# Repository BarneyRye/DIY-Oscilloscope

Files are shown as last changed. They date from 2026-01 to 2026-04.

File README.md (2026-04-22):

# DIY Osciliscope
Design based on a **STM32F405RGT6**, with 2 options to connect up to 2 seperate leads. <br>
Used a 240x320 TFT ILI9341 screen module over SPI. <br>
[Example Screen: 2.8-inch SPI LCD Module 240 * 320 TFT Module ILI9341](https://www.amazon.co.uk/DIGISHUO-2-8-inch-ILI9341-occupies-Display/dp/B0DPZ3B171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) <br>
Max inputs of +/- 20V, 40Vpp. <br>
USB-C connection for power or streaming waveform to seprate device.

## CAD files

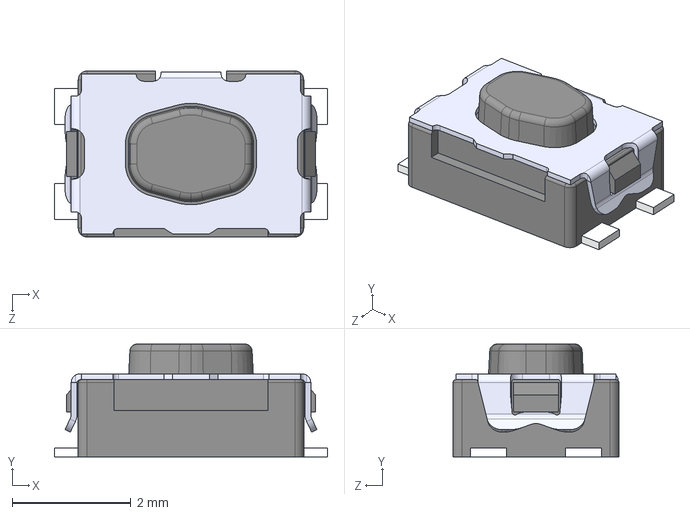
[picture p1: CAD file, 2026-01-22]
Osciliscope PCB/Parts/03Models/KMR221GLFS.step
4.60 x 1.90 x 2.80 mm

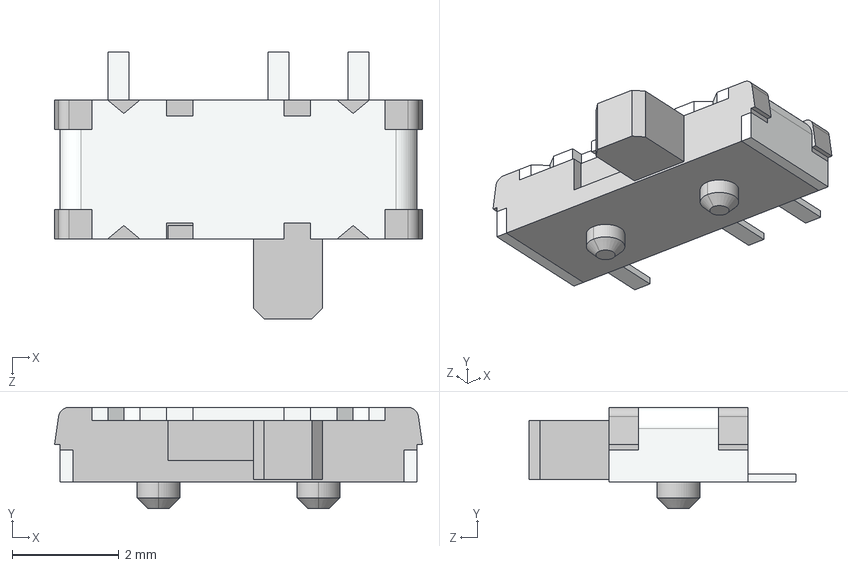
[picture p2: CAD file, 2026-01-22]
Osciliscope PCB/Parts/03Models/SSSS810701.stp
6.90 x 1.90 x 5.00 mm

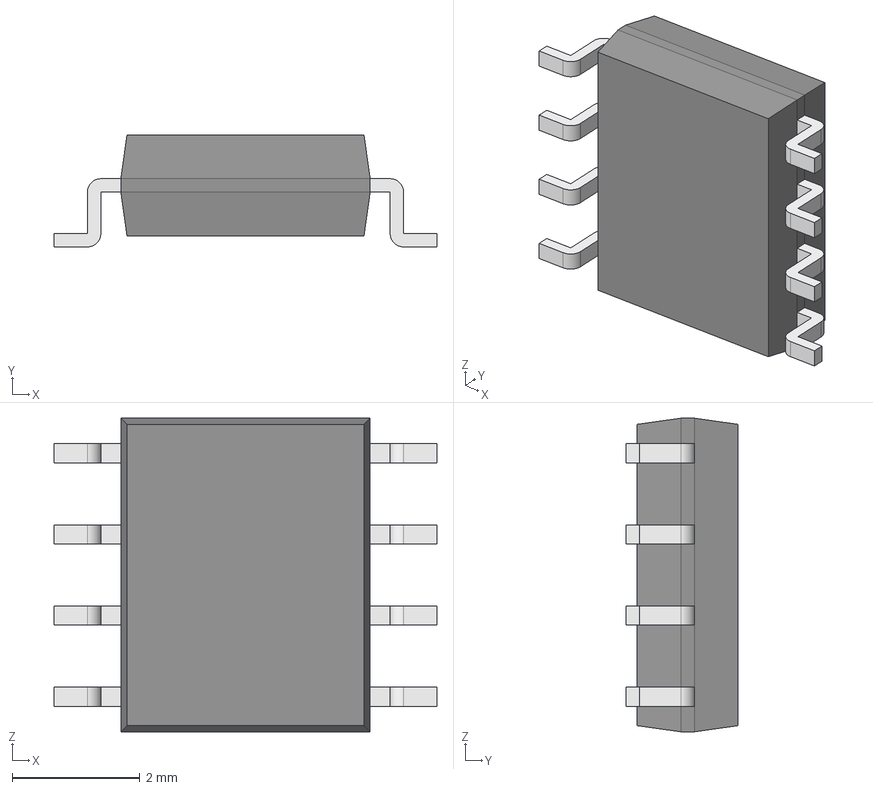
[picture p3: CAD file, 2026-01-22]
Osciliscope PCB/Parts/03Models/OPA350UA_2K5G4.step
5.99 x 1.75 x 4.91 mm
Body001 (Mirror #1) x 4
XY-plane x 12
X-axis x 12

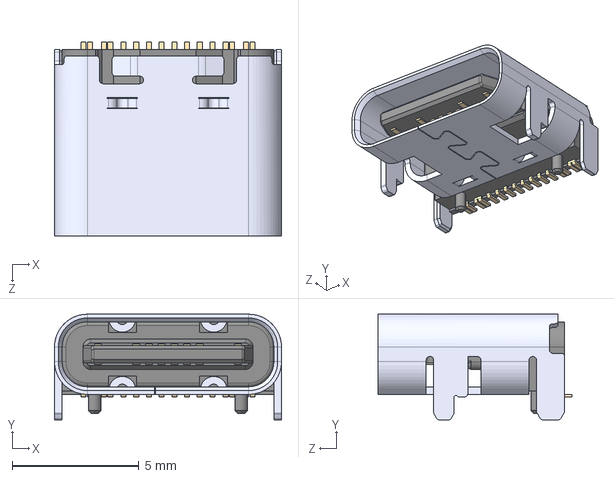
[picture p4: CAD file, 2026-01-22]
Osciliscope PCB/Parts/03Models/TYPE-C_16PIN_2MD__073_.step
8.94 x 4.16 x 7.65 mm

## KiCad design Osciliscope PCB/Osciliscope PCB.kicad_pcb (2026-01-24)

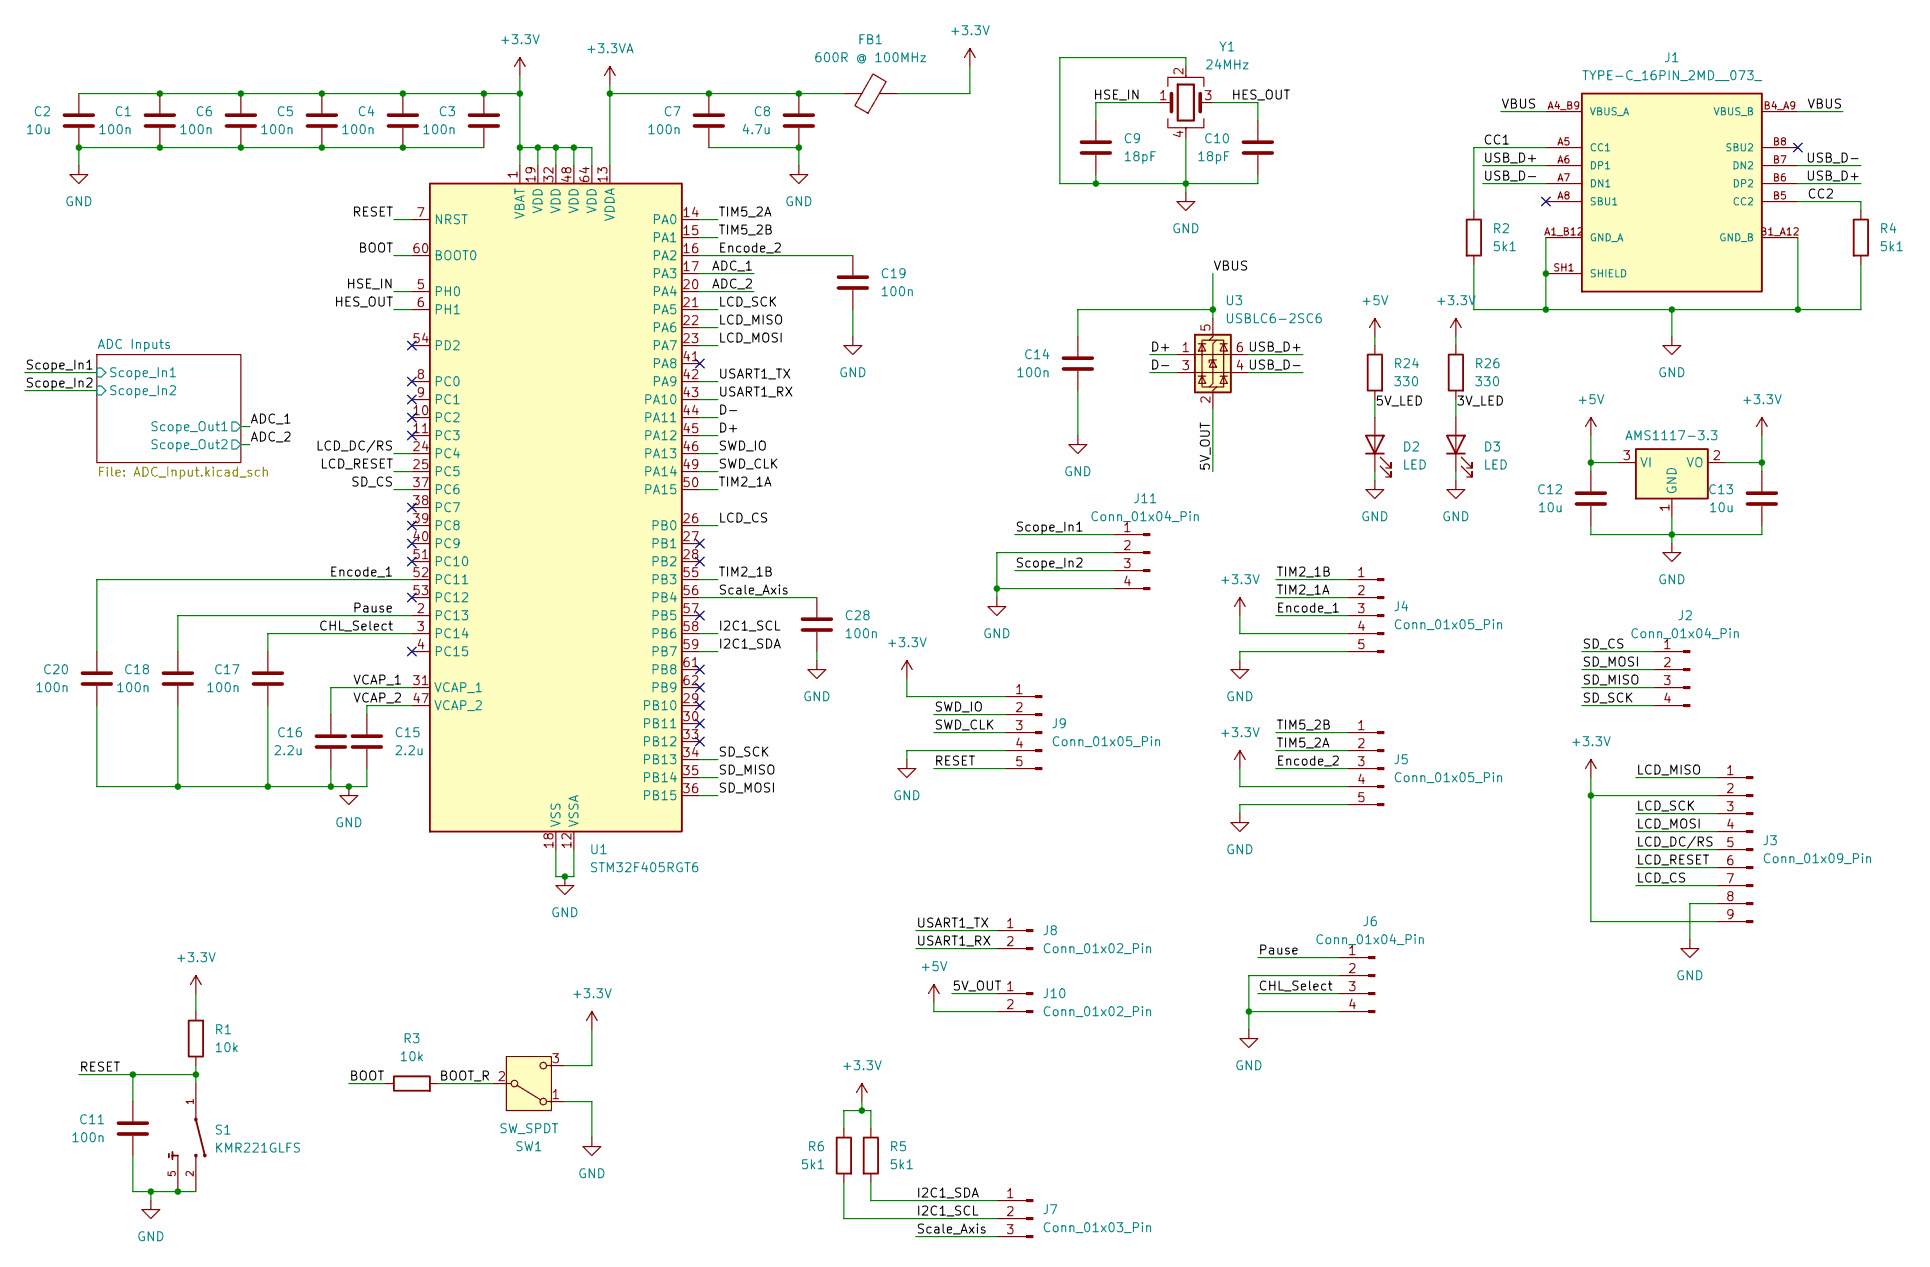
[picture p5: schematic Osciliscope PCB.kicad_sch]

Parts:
C1, C3, C4, C5, C6, C7, C11, C14, C17, C18, C19, C20, C28: 100n; C_0402_1005Metric
C2, C12, C13: 10u; C_0805_2012Metric
C8: 4.7u; C_0603_1608Metric
C9, C10: 18pF; C_0402_1005Metric
C15, C16: 2.2u; C_0603_1608Metric
D2, D3: LED; C_0805_2012Metric
FB1: 600R @ 100MHz; C_0805_2012Metric
J1: TYPE-C_16PIN_2MD__073_; SHOUHAN_TYPE-C_16PIN_2MD__073_; Part NO. C393939
J2, J6, J11: Conn_01x04_Pin; PinHeader_1x04_P2.54mm_Vertical; Part NO. C2905435
J3: Conn_01x09_Pin; PinHeader_1x09_P2.54mm_Vertical; Part NO. C2932701
J4, J5, J9: Conn_01x05_Pin; PinHeader_1x05_P2.54mm_Vertical; Part NO. C2932699
J7: Conn_01x03_Pin; PinHeader_1x03_P2.54mm_Vertical; Part NO. C2932698
J8, J10: Conn_01x02_Pin; PinHeader_1x02_P2.54mm_Vertical; Part NO. C2932698
R1, R3: 10k; C_0402_1005Metric
R2, R4, R5, R6: 5k1; C_0402_1005Metric
R24, R26: 330; C_0603_1608Metric
S1: KMR221GLFS; SW_KMR221GLFS; Part NO. C72443
SW1: SW_SPDT; SW-SMD_SSSS810701; Part NO. C97433
U1: STM32F405RGT6; LQFP-64_10x10mm_P0.5mm; Part NO. C15742
U2: AMS1117-3.3; SOT-223-3_TabPin2; Part NO. C2688239
U3: USBLC6-2SC6; SOT-23-6; Part NO. C7519
Y1: 24MHz; Crystal_SMD_3225-4Pin_3.2x2.5mm; Part NO. C70590

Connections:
+3.3V: C1.1, C2.1, C3.1, C4.1, C5.1, C6.1, C13.1, FB1.2, J3.2, J3.9, J4.4, J5.4, J9.1, R1.2, R5.1, R6.1, R26.1, SW1.3 (C), U1.1 (VBAT), U1.19 (VDD), U1.32 (VDD), U1.48 (VDD), U1.64 (VDD), U2.2 (VO); also elsewhere on the board
+3.3VA: C7.1, C8.1, FB1.1, U1.13 (VDDA)
+5V: C12.1, J10.2, R24.1, U2.3 (VI)
/3V_LED: D3.2 (A), R26.2
/5V_LED: D2.2 (A), R24.2
/5V_OUT: J10.1, U3.2 (GND)
/ADC_1: U1.17 (PA3); also elsewhere on the board
/ADC_2: U1.20 (PA4); also elsewhere on the board
/BOOT: R3.1, U1.60 (BOOT0)
/BOOT_R: R3.2, SW1.2 (B)
/CC1: J1.A5 (CC1), R2.1
/CC2: J1.B5 (CC2), R4.1
/CHL_Select: C17.1, J6.3, U1.3 (PC14)
/D+: U1.45 (PA12), U3.1 (I/O1)
/D-: U1.44 (PA11), U3.3 (I/O2)
/Encode_1: C20.1, J4.3, U1.52 (PC11)
/Encode_2: C19.1, J5.3, U1.16 (PA2)
/HES_OUT: C10.1, U1.6 (PH1), Y1.3
/HSE_IN: C9.1, U1.5 (PH0), Y1.1
/I2C1_SCL: J7.2, R6.2, U1.58 (PB6)
/I2C1_SDA: J7.1, R5.2, U1.59 (PB7)
/LCD_CS: J3.7, U1.26 (PB0)
/LCD_DC/RS: J3.5, U1.24 (PC4)
/LCD_MISO: J3.1, U1.22 (PA6)
/LCD_MOSI: J3.4, U1.23 (PA7)
/LCD_RESET: J3.6, U1.25 (PC5)
/LCD_SCK: J3.3, U1.21 (PA5)
/Pause: C18.1, J6.1, U1.2 (PC13)
/RESET: C11.1, J9.5, R1.1, S1.1, S1.4, U1.7 (NRST)
/SD_CS: J2.1, U1.37 (PC6)
/SD_MISO: J2.3, U1.35 (PB14)
/SD_MOSI: J2.2, U1.36 (PB15)
/SD_SCK: J2.4, U1.34 (PB13)
/SWD_CLK: J9.3, U1.49 (PA14)
/SWD_IO: J9.2, U1.46 (PA13)
/Scale_Axis: C28.1, J7.3, U1.56 (PB4)
/Scope_In1: J11.1; also elsewhere on the board
/Scope_In2: J11.3; also elsewhere on the board
/TIM2_1A: J4.2, U1.50 (PA15)
/TIM2_1B: J4.1, U1.55 (PB3)
/TIM5_2A: J5.2, U1.14 (PA0)
/TIM5_2B: J5.1, U1.15 (PA1)
/USART1_RX: J8.2, U1.43 (PA10)
/USART1_TX: J8.1, U1.42 (PA9)
/USB_D+: J1.A6 (DP1), J1.B6 (DP2), U3.6 (I/O1)
/USB_D-: J1.A7 (DN1), J1.B7 (DN2), U3.4 (I/O2)
/VBUS: C14.1, J1.A4_B9 (VBUS_A), J1.B4_A9 (VBUS_B), U3.5 (VBUS)
/VCAP_1: C16.1, U1.31 (VCAP_1)
/VCAP_2: C15.1, U1.47 (VCAP_2)
GND: C1.2, C2.2, C3.2, C4.2, C5.2, C6.2, C7.2, C8.2, C9.2, C10.2, C11.2, C12.2, C13.2, C14.2, C15.2, C16.2, C17.2, C18.2, C19.2, C20.2, C28.2, D2.1 (K), D3.1 (K), J1.A1_B12 (GND_A), J1.B1_A12 (GND_B), J1.SH1 (SHIELD), J1.SH2 (SHIELD), J1.SH3 (SHIELD), J1.SH4 (SHIELD), J3.8, J4.5, J5.5, J6.2, J6.4, J9.4, J11.2, J11.4, R2.2, R4.2, S1.2, S1.3, S1.5, SW1.1 (A), U1.12 (VSSA), U1.18 (VSS), U1.63 (VSS), U2.1 (GND), Y1.2, Y1.4; also elsewhere on the board

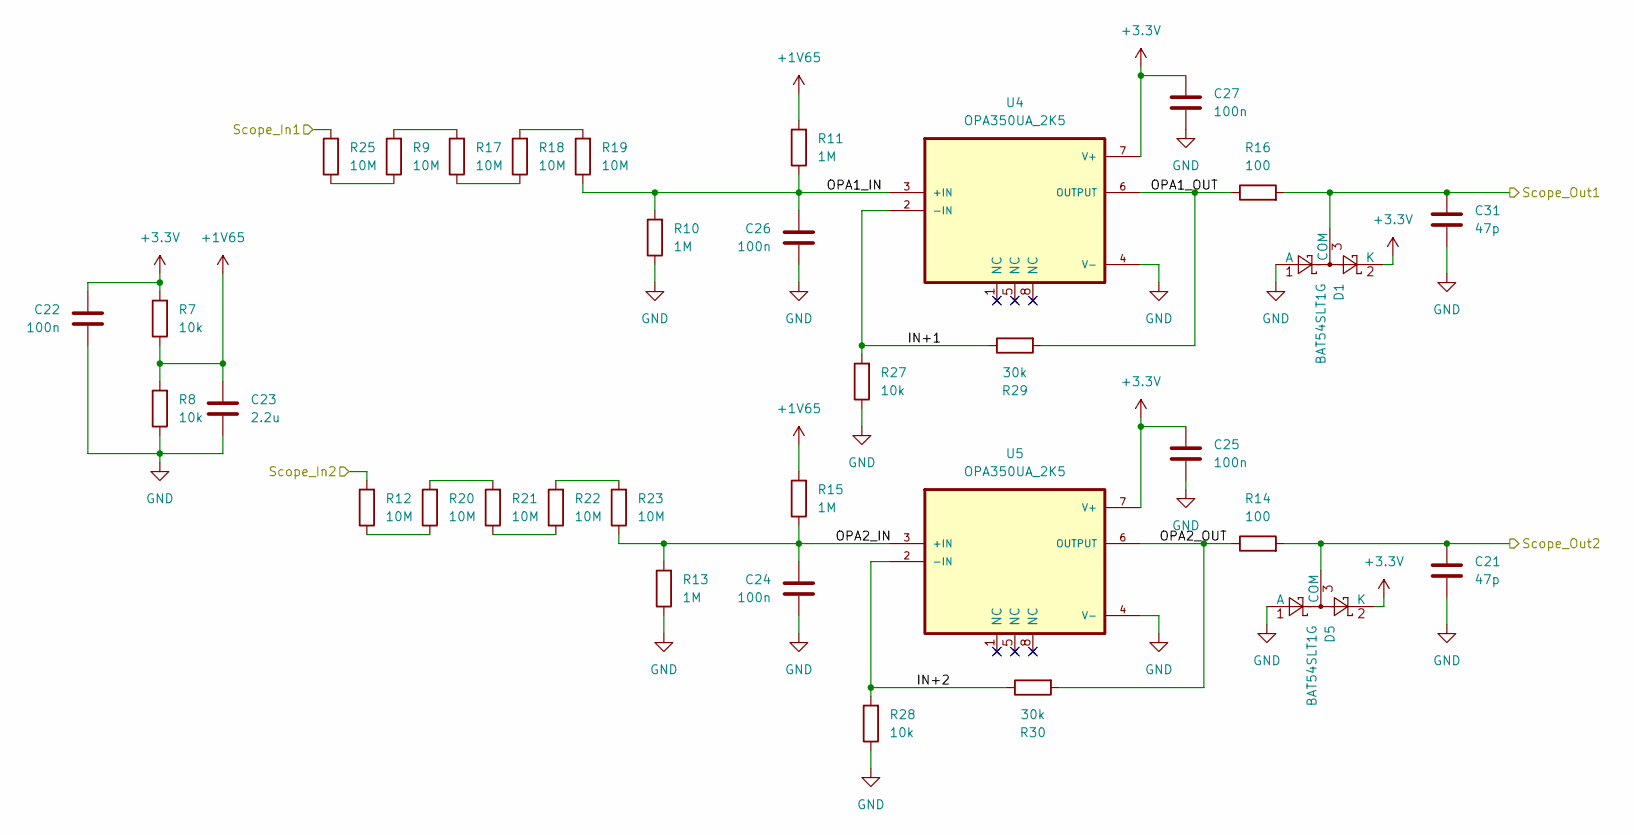
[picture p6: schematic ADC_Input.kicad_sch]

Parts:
C21, C31: 47p; C_0402_1005Metric
C22, C24, C25, C26, C27: 100n; C_0402_1005Metric
C23: 2.2u; C_0603_1608Metric
D1, D5: BAT54SLT1G; SOT-23
R7, R8, R27, R28: 10k; C_0402_1005Metric
R9, R12, R17, R18, R19, R20, R21, R22, R23, R25: 10M; C_0402_1005Metric
R10, R11, R13, R15: 1M; C_0402_1005Metric
R14, R16: 100; C_0402_1005Metric
R29, R30: 30k; C_0402_1005Metric
U4, U5: OPA350UA_2K5; SOIC127P599X175-8N; Part NO. C13388

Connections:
+1V65: C23.1, R7.1, R8.2, R11.2, R15.2
+3.3V: C22.1, C25.1, C27.1, D1.2 (K), D5.2 (K), R7.2, U4.7 (V+), U5.7 (V+); also elsewhere on the board
/ADC Inputs/IN+1: R27.2, R29.1, U4.2 (-IN)
/ADC Inputs/IN+2: R28.2, R30.1, U5.2 (-IN)
/ADC Inputs/OPA1_IN: C26.1, R10.2, R11.1, R19.1, U4.3 (+IN)
/ADC Inputs/OPA1_OUT: R16.1, R29.2, U4.6 (OUTPUT)
/ADC Inputs/OPA2_IN: C24.1, R13.2, R15.1, R23.1, U5.3 (+IN)
/ADC Inputs/OPA2_OUT: R14.1, R30.2, U5.6 (OUTPUT)
/ADC_1: C31.1, D1.3 (COM), R16.2; also elsewhere on the board
/ADC_2: C21.1, D5.3 (COM), R14.2; also elsewhere on the board
/Scope_In1: R25.2; also elsewhere on the board
/Scope_In2: R12.2; also elsewhere on the board
GND: C21.2, C22.2, C23.2, C24.2, C25.2, C26.2, C27.2, C31.2, D1.1 (A), D5.1 (A), R8.1, R10.1, R13.1, R27.1, R28.1, U4.4 (V-), U5.4 (V-); also elsewhere on the board
unnamed: R12.1, R20.1
unnamed: R17.1, R18.1
unnamed: R9.2, R17.2
unnamed: R18.2, R19.2
unnamed: R20.2, R21.2
unnamed: R21.1, R22.1
unnamed: R22.2, R23.2
unnamed: R9.1, R25.1

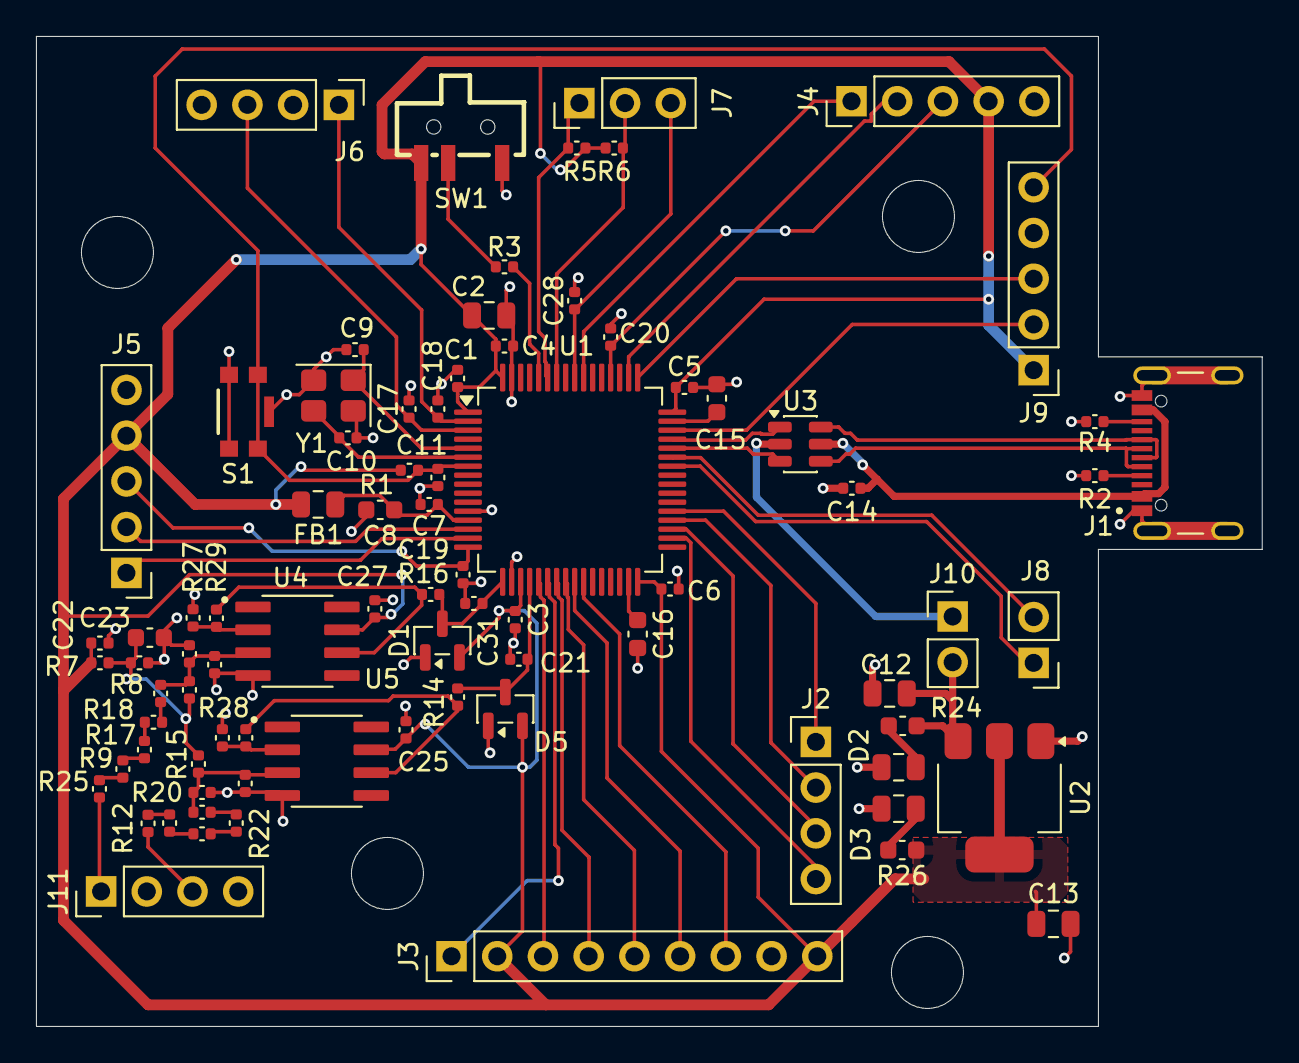
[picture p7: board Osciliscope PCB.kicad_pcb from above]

Board: 2 copper layers, 68.1 x 55.0 mm, 83 parts (0 on the bottom side), 65 nets.

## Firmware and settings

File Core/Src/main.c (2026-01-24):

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
/* Includes ------------------------------------------------------------------*/
#include "main.h"
#include "adc.h"
#include "dma.h"
#include "i2c.h"
#include "spi.h"
#include "tim.h"
#include "usart.h"
#include "usb_otg.h"
#include "gpio.h"

/* USER CODE BEGIN Includes */
#include <math.h>
#include <stdlib.h>
#include <stdint.h>

/* USER CODE END Includes */

/* USER CODE BEGIN PD */
#define PAUSE_PIN GPIOC, GPIO_PIN_13
#define CHL_SELECT_PIN GPIOC, GPIO_PIN_14
#define HSE_IN_PIN GPIOH, GPIO_PIN_0
#define HSE_OUT_PIN GPIOH, GPIO_PIN_1
#define TIM5_CH1_PIN GPIOA, GPIO_PIN_0
#define TIM5_CH2_PIN GPIOA, GPIO_PIN_1
#define ENCODE2_PIN GPIOA, GPIO_PIN_2
#define WAVEIN1_PIN GPIOA, GPIO_PIN_3
#define WAVEIN2_PIN GPIOA, GPIO_PIN_4
#define LCD_SCK_PIN GPIOA, GPIO_PIN_5
#define LCD_MISO_PIN GPIOA, GPIO_PIN_6
#define LCD_MOSI_PIN GPIOA, GPIO_PIN_7
#define LCD_DCRS_PIN GPIOC, GPIO_PIN_4
#define LCD_RESET_PIN GPIOC, GPIO_PIN_5
#define LCD_CS_PIN GPIOB, GPIO_PIN_0
#define SD_SCK_PIN GPIOB, GPIO_PIN_13
#define SD_MISO_PIN GPIOB, GPIO_PIN_14
#define SD_MOSI_PIN GPIOB, GPIO_PIN_15
#define SD_CS_PIN GPIOC, GPIO_PIN_6
#define USART1_TX_PIN GPIOA, GPIO_PIN_9
#define USART1_RX_PIN GPIOA, GPIO_PIN_10
#define USB_DM_PIN GPIOA, GPIO_PIN_11
#define USB_DP_PIN GPIOA, GPIO_PIN_12
#define SWD_IO_PIN GPIOA, GPIO_PIN_13
#define SWD_CLK_PIN GPIOA, GPIO_PIN_14
#define TIM2_CH1_PIN GPIOA, GPIO_PIN_15
#define ENCODE1_PIN GPIOC, GPIO_PIN_11
#define TIM2_CH2_PIN GPIOB, GPIO_PIN_3
#define SCALE_AXIS_PIN GPIOB, GPIO_PIN_4
#define I2C1_SCL_PIN GPIOB, GPIO_PIN_6
#define I2C1_SDA_PIN GPIOB, GPIO_PIN_7

#define ADC_12BIT 4095.0f
#define VRef 3.3f //V
#define ATTENUATION_FACTOR 51.0f //51:1
#define OP_AMP_GAIN 4.0f //Gain of OP-AMP
#define ADC_BUFFER_SIZE 4096 //Size of ADC DMA buffer
#define TIM3_CLK 84000000 //Timer 3 Clock Frequency

#define X_DIVISIONS 20.0f // 20 X divisions
#define Y_DIVISIONS 10.0f // +/- 10 Y divisions
//50Hz input min, 25KHz input max
//At least 10 Waveforms, meaning 2 div per wavefront
//Min 1 Waveform, meaning 20 div per wavefront
//Max T(1/50) * (1/2) = 0.01s, Min T(1/25K) * 1/20 = 2e-6s = 0.000002
static const float xdiv_Levels[] = {0.000002f, 0.0000025f, 0.000003f, 0.000004f, 0.000005f, 0.000008f, 0.00001f, 0.000015f, 0.00002f, 0.000025f, 0.00003f, 0.00004f, 0.00005f, 0.00008f, 0.0001f, 0.00015f, 0.0002f, 0.00025f, 0.0003f, 0.0004f, 0.0005f, 0.0008f, 0.001f, 0.0015f, 0.002f, 0.0025f, 0.003f, 0.004f, 0.005f, 0.008f, 0.01f};
//Min is roughly resolution, Max is 20v Peak / no. divisions = 20/10 = 2V
static const float ydiv_Levels[] = {0.01f, 0.02f, 0.03f, 0.04f, 0.05f, 0.08f, 0.1f, 0.2f, 0.3f, 0.4f, 0.5f, 0.8f, 1.0f, 1.2f, 1.5f, 1.6f, 2.0f};
#define COUNT_PER_STEP 4 //Count increase on encoder timer per encoder step

typedef enum {
  SCOPE_ARMED = 0,
  SCOPE_TRIGGERED,
  SCOPE_WAITING
} scope_state_t;
/* USER CODE END PD */

/* USER CODE BEGIN PM */
#define XDIV_COUNT (sizeof(xdiv_Levels)/sizeof(xdiv_Levels[0]))
#define YDIV_COUNT (sizeof(ydiv_Levels)/sizeof(ydiv_Levels[0]))
/* USER CODE END PM */


/* USER CODE BEGIN PV */
  float BIAS_VOLTAGE = 1.65f; //Bias Voltage
  volatile uint8_t CHL_Select_State = 0; //Channel Select Button State
  volatile uint8_t Pause_State = 0; //Pause Button State
  volatile uint8_t Auto_Scale_Y_State = 0; //Auto Scale Y State
  volatile uint8_t Scale_Axis_State = 0; //Scale Axis Button State 0->x, 1->y
  volatile float Trig_Voltage = 0.0f; //Set Initial Trigger Voltage
  volatile uint8_t Trig_Flag = 0;
  volatile uint16_t Trig_ADC_Value = 2048;
  volatile scope_state_t scope_state = SCOPE_ARMED;
  float Sample_Rate; //Hz
  float Sample_period; //s
  uint8_t Screen_Change_Flag = 1; //Flag to indicate screen change
/* USER CODE END PV */

void SystemClock_Config(void);
/* USER CODE BEGIN PFP */
void VBias_Init(uint16_t *adc_buffer);
void Set_Axis_Div(float *buffer, float *xDIV, float *yDIV, uint16_t length);
void Set_Trig_Value(void);
void ADC_Convert(uint16_t *adc_input, float *Vin, uint16_t DMA_index);
float VmaxABS(float *buffer, uint16_t length);
float Auto_Scale_Y(float *buffer, uint16_t length, int *ylocation);
void ADC_SetTrigger(void);
void DWT_Init(void);
uint32_t Micros(void);

/* USER CODE END PFP */

/**
  * @brief  The application entry point.
  * @retval int
  */
int main(void)
{

  /* MCU Configuration--------------------------------------------------------*/

  /* Reset of all peripherals, Initializes the Flash interface and the Systick. */
  HAL_Init();

  /* Configure the system clock */
  SystemClock_Config();

  /* Initialize all configured peripherals */
  MX_GPIO_Init();
  MX_DMA_Init();
  MX_SPI1_Init();
  MX_USART1_UART_Init();
  MX_USB_OTG_FS_PCD_Init();
  MX_ADC1_Init();
  MX_I2C1_Init();
  MX_SPI2_Init();
  MX_TIM2_Init();
  MX_TIM5_Init();
  MX_TIM3_Init();
  /* USER CODE BEGIN 2 */

  HAL_TIM_Base_Start(&htim3); //Start Timer 3 for ADC trigger
  static uint16_t adc_buffer[ADC_BUFFER_SIZE]; //ADC DMA buffer
  HAL_ADC_Start_DMA(&hadc1, (uint32_t*)adc_buffer, ADC_BUFFER_SIZE); //Start ADC with DMA
  HAL_Delay(100); //Delay for ADC to stabilise and fill buffer
  VBias_Init(adc_buffer); //Initialise Bias Voltage 

  HAL_TIM_Encoder_Start(&htim2, TIM_CHANNEL_ALL); //Start Encoder 1
  __HAL_TIM_SET_COUNTER(&htim2, 0x80000000); //Set Encoder 1 counter to middle value
  HAL_TIM_Encoder_Start(&htim5, TIM_CHANNEL_ALL); //Start Encoder 2
  __HAL_TIM_SET_COUNTER(&htim5, 0x80000000); //Set Encoder 2 counter to middle value

  static float Vin_buffer[ADC_BUFFER_SIZE]; //Scaled Voltage buffer
  ADC_Convert(adc_buffer, Vin_buffer, ADC_BUFFER_SIZE);

  yDIV = 0.5f; //Initial Y Division setting
  xDIV = 0.0002f; //Initial X Division setting
  Set_Axis_Div(Vin_buffer, &xDIV, &yDIV, ADC_BUFFER_SIZE); //Initialise Axis Division setting
  Set_Trig_Value(); //Initialise Trigger Value setting

  ILI9341_Init();
  ILI9341_Clear(BLACK);
  ILI9341_ClearUI();
  ILI9341_UpdateVals(xDIV, yDIV, Trig_Voltage);
  ILI9341_DrawAxis(Y_DIVISIONS, X_DIVISIONS);

  static float plot_buffer[ADC_BUFFER_SIZE/2];

  DWT_Init(); //Initialize DWT for Micros() function
  uint32_t Last_Trig_Time = Micros(); 

  uint16_t DMA_Index = 0; //Get current DMA index
  /* USER CODE END 2 */

  /* Infinite loop */
  /* USER CODE BEGIN WHILE */
  while (1)
  {
    /* USER CODE END WHILE */

    /* USER CODE BEGIN 3 */
    uint32_t Total_Display_Time = (uint32_t)(xDIV * X_DIVISIONS * 1e6f); //Total time (us) displayed on screen
    if (Trig_Flag) {
      Trig_Flag = 0;
      HAL_ADC_Stop_DMA(&hadc1); //Stop ADC DMA
      DMA_Index = ADC_BUFFER_SIZE - hdma_adc1.Instance->NDTR; //Get current DMA index
      ADC_Convert(adc_buffer, Vin_buffer, DMA_Index); //Convert ADC values to Voltages
      HAL_ADC_Start_DMA(&hadc1, (uint32_t*)adc_buffer, ADC_BUFFER_SIZE); //Restart ADC DMA
      Last_Trig_Time = Micros();
      scope_state = SCOPE_WAITING;
    }
    if (scope_state == SCOPE_WAITING) {
      if ((Micros() - Last_Trig_Time) >= Total_Display_Time*1.5f) {
        volatile uint32_t temp_void = hadc1.Instance->DR; //Read DR to clear potential overrun flag
        (void)temp_void;
        __HAL_ADC_ENABLE_IT(&hadc1, ADC_IT_AWD);
        scope_state = SCOPE_ARMED;
      }
    }

	  if (!CHL_Select_State){
		  for (uint16_t i=0; i<DMA_Index/2; i++){
			  plot_buffer[i] = Vin_buffer[2*i];
		  }
	  }
	  else {
		  for (uint16_t i=0; i<DMA_Index/2; i++){
			  plot_buffer[i] = Vin_buffer[2*i+1];
		  }
	  }

    
    Wavefront_Index = Find_Rising_Edge(plot_buffer, DMA_Index/2); //Find Rising Edge for Triggering
    if (Wavefront_Index >= DMA_Index/2) {
      Wavefront_Index = 0; //No Trigger Found, set to 0
    }
    static float plot_volts[ADC_BUFFER_SIZE/2];
    for (uint16_t i=0; i<(DMA_Index/2)-Wavefront_Index; i++) {
      plot_volts[i] = plot_buffer[Wavefront_Index + i];
    }

	  Set_Axis_Div(plot_volts, &xDIV, &yDIV, (DMA_Index/2)-Wavefront_Index); //Update Axis Division setting
	  Set_Trig_Value(); //Update Trigger Value setting
    if (Screen_Change_Flag) {
      Screen_Change_Flag = 0;
      ILI9341_UpdateVals(xDIV, yDIV, Trig_Voltage);
    }
	  if (!Pause_State){
      ILI9341_ClearWaveform();
		  ILI9341_DrawAxis(Y_DIVISIONS, X_DIVISIONS);
		  ILI9341_PlotWaveform(plot_volts,xDIV,yDIV,RED);
	  }
  }
  /* USER CODE END 3 */
}

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
/* USER CODE BEGIN 4 */
void HAL_GPIO_EXTI_Callback(uint16_t GPIO_Pin) {
    switch(GPIO_Pin)
    {
        case GPIO_PIN_14: // PC14 -- CHL_Select Button
            // handle PC14 interrupt
        	CHL_Select_State = !CHL_Select_State;
        	ADC_SetTrigger();
            break;
        case GPIO_PIN_13: // PC13 -- Pause Button
            // handle PC13 interrupt
        	Pause_State = !Pause_State;
            break;
        case GPIO_PIN_11: // PC11 -- Encoder 1 Button
            // handle PC11 interrupt
        	Auto_Scale_Y_State = 1;
            break;
        case GPIO_PIN_4:  // PB4 -- Scale Axis Button
            // handle PB4 interrupt
        	Scale_Axis_State = !Scale_Axis_State;
            break;
        case GPIO_PIN_2:  // PA2 -- Encoder 2 Button
            // handle PA2 interrupt
        	Trig_Voltage = 0.0f; //Reset Trigger Voltage
            break;
    }
}

void HAL_ADC_LevelOutOfWindowCallback(ADC_HandleTypeDef* hadc) {
  if (hadc->Instance == ADC1) {
		//Trigger
    if (scope_state == SCOPE_ARMED) {
		    Trig_Flag = 1;
        scope_state = SCOPE_TRIGGERED;
        __HAL_ADC_DISABLE_IT(&hadc1, ADC_IT_AWD);
		  }
	  }
  return;
}

void VBias_Init(uint16_t *adc_buffer) {
	//Initialise Bias Voltage
	uint32_t adc_sum = 0;
	for (int i=0; i<ADC_BUFFER_SIZE; i++) {
		adc_sum += adc_buffer[i];
	}
	BIAS_VOLTAGE = ((float)adc_sum / ADC_BUFFER_SIZE) * (VRef / ADC_12BIT);
	return;
}

void Set_Axis_Div(float *buffer, float *xDIV, float *yDIV, uint16_t length) {
	static int ylocation = 4; //Initial Y division index
  static int xlocation = 16; //Initial X division index
  if (Auto_Scale_Y_State) {
		*yDIV = Auto_Scale_Y(buffer, length, &ylocation); //Auto Scale Y if enabled
		Auto_Scale_Y_State = 0; //Reset Auto Scale Y State
    Screen_Change_Flag = 1;
    return;
	}
  static uint32_t TIM2_Count = 0;
	uint32_t TIM2_New_Count = __HAL_TIM_GET_COUNTER(&htim2);
	if (TIM2_Count == 0) {
		TIM2_Count = __HAL_TIM_GET_COUNTER(&htim2);

	}
	else if (TIM2_New_Count != TIM2_Count) {
		int steps = ((int32_t)TIM2_New_Count - (int32_t)TIM2_Count) / COUNT_PER_STEP;
		TIM2_Count = TIM2_New_Count;
		if (Scale_Axis_State == 0) {
			//X-Axis Scaling
			//Adjust Time/Div based on steps
			xlocation += steps;
			if (xlocation >= (XDIV_COUNT - 1)) {xlocation = XDIV_COUNT - 1;}
			else if (xlocation < 0) {xlocation = 0;}
			*xDIV = xdiv_Levels[xlocation];
      Screen_Change_Flag = 1;
      float Total_Display_Time = (*xDIV) * X_DIVISIONS; //Total time (s) displayed on screen
      Sample_period = Total_Display_Time / (ADC_BUFFER_SIZE/4.0f); //Calculate Sample Period based on 2 channels and 2x bufferring
      Sample_Rate = (uint32_t)(1.0f / Sample_period); //Calculate Sample Rate
      Scope_SetSampleRate(Sample_Rate); //Set Sample Rate
		}
		else {
			//Y-Axis Scaling
			//Adjust V/Div based on steps
			ylocation += steps;
			if (ylocation >= (YDIV_COUNT - 1)) {ylocation = YDIV_COUNT - 1;}
			else if (ylocation < 0) {ylocation = 0;}
			*yDIV = ydiv_Levels[ylocation];
      Screen_Change_Flag = 1;
		}
	}
}

void Set_Trig_Value(void) {
	static uint32_t TIM5_Count = 0;
	uint32_t TIM5_New_Count = __HAL_TIM_GET_COUNTER(&htim5);
	if (TIM5_Count == 0) {
		TIM5_Count = __HAL_TIM_GET_COUNTER(&htim5);
	}
	else if (TIM5_New_Count != TIM5_Count) {
		int steps = ((int32_t)TIM5_New_Count - (int32_t)TIM5_Count) / 4;
		TIM5_Count = TIM5_New_Count;
		float Temp_Trig_Voltage = Trig_Voltage + (float)steps*0.01f;
		if (Temp_Trig_Voltage > 20.0f) {Trig_Voltage = 20.0f;}
		else if (Temp_Trig_Voltage < -20.0f) {Trig_Voltage = -20.0f;}
		else {Trig_Voltage = Temp_Trig_Voltage;}

		float Trig_Voltage_Adj = (Trig_Voltage / ATTENUATION_FACTOR * OP_AMP_GAIN) + BIAS_VOLTAGE;
		Trig_ADC_Value = (uint16_t)(Trig_Voltage_Adj * (ADC_12BIT/VRef));
    if (Trig_ADC_Value > 4095) {Trig_ADC_Value = 4095;}
		ADC_SetTrigger();
    Screen_Change_Flag = 1;
	}
}

void ADC_Convert(uint16_t *adc_input, float *Vin, uint16_t DMA_index) {
	//Scale ADC input based on schematic design
	//ADC input range: 0-3.3V (0-4095), VRef = 3.3V
	//Scope input range: +/-20v
	//Attenuation factor: 51:1
	//Bias: 3.3v/2 = 1.65v
	//OP-AMP Gain = 4
	//Vin = (Input-Bias)*(Attenuation Factor)/(OP-AMP Gain)
	for (int i=0; i<DMA_index; i++){
		float Vadc = (float)adc_input[i] * (VRef/ADC_12BIT); //Convert ADC value to voltage
		Vin[i] = (Vadc - BIAS_VOLTAGE) * (ATTENUATION_FACTOR) / (OP_AMP_GAIN); //Multiply by attenuation factor and divide by OP-AMP gain
	}
}

float VmaxABS(float *buffer, uint16_t length) {
	float max = fabsf(buffer[0]);
	for (int i=1; i<length; i++) {
		if (fabsf(buffer[i]) > max) {
			max = fabsf(buffer[i]);
		}
	}
	return max;
}

float Auto_Scale_Y(float *buffer, uint16_t length, int *ylocation) {
	float Vpp = 2* VmaxABS(buffer, length);
	//Screen Height is 240 pixels
	//Usable height = 200 pixels (20 pixels margin top and bottom)
	//Scale such that Vpp fits in 200 pixels
	//Similarly +/- 10 divisions vertically from #define Y_DIVISIONS
	//Max V/div = 20V/10 = 2V/div
	//Min V/div = 0.1V/10 = 0.01V/div //Roughly Corresponds to accuracy of ADC
	float V_div = Vpp / (2.0f * (float)Y_DIVISIONS); //Volts per division
	for (uint8_t i=0; i<YDIV_COUNT; i++) {
		if (V_div <= ydiv_Levels[i]) {
			*ylocation = i;
			return ydiv_Levels[i];
		}
	}
	return ydiv_Levels[YDIV_COUNT - 1];
}

void ADC_SetTrigger(void) {

	uint32_t CHANNEL;
	if (!CHL_Select_State) {CHANNEL = ADC_CHANNEL_3;}
	else {CHANNEL = ADC_CHANNEL_4;}

	ADC_AnalogWDGConfigTypeDef awdConfig;
	awdConfig.WatchdogNumber = ADC_ANALOGWATCHDOG_1;
	awdConfig.Channel = CHANNEL;
	awdConfig.ITMode = ENABLE;
	awdConfig.HighThreshold = Trig_ADC_Value;
	awdConfig.LowThreshold  = 0; // keep low
	HAL_ADC_AnalogWDGConfig(&hadc1, &awdConfig);
}

void DWT_Init(void) {
  CoreDebug->DEMCR |= CoreDebug_DEMCR_TRCENA_Msk; // Enable the trace and debug block
  DWT->CYCCNT = 0; // Reset the cycle counter
  DWT->CTRL |= DWT_CTRL_CYCCNTENA_Msk; // Enable the cycle counter
}

uint32_t Micros(void) {
  return DWT->CYCCNT / (SystemCoreClock / 1000000);
}

uint16_t Find_Rising_Edge(float *buffer, uint16_t DMA_Index) {
  for (uint16_t i = 1; i < DMA_Index; i++) {
    if (buffer[i - 1] < Trig_Voltage && buffer[i] >= Trig_Voltage) {
      return i;
    }
  }
  return 0; // No rising edge found
}

void Scope_SetSampleRate(uint32_t fs) {
  if (fs<1) {fs = 1;}
  uint32_t arr = (TIM3_CLK / fs) - 1;

  __HAL_TIM_DISABLE(&htim3);
  __HAL_TIM_SET_AUTORELOAD(&htim3, arr);
  __HAL_TIM_SET_COUNTER(&htim3, 0);
  __HAL_TIM_ENABLE(&htim3);
}
/* USER CODE END 4 */
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


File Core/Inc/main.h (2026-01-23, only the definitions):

#define Pause_Pin GPIO_PIN_13
#define Pause_GPIO_Port GPIOC
#define CHL_Select_Pin GPIO_PIN_14
#define CHL_Select_GPIO_Port GPIOC
#define Encode_2_Pin GPIO_PIN_2
#define Encode_2_GPIO_Port GPIOA
#define LCD_SCK_Pin GPIO_PIN_5
#define LCD_SCK_GPIO_Port GPIOA
#define LCD_MISO_Pin GPIO_PIN_6
#define LCD_MISO_GPIO_Port GPIOA
#define LCD_MOSI_Pin GPIO_PIN_7
#define LCD_MOSI_GPIO_Port GPIOA
#define LCD_DC_RS_Pin GPIO_PIN_4
#define LCD_DC_RS_GPIO_Port GPIOC
#define LCD_RESET_Pin GPIO_PIN_5
#define LCD_RESET_GPIO_Port GPIOC
#define LCD_CS_Pin GPIO_PIN_0
#define LCD_CS_GPIO_Port GPIOB
#define SD_SCK_Pin GPIO_PIN_13
#define SD_SCK_GPIO_Port GPIOB
#define SD_MISO_Pin GPIO_PIN_14
#define SD_MISO_GPIO_Port GPIOB
#define SD_MOSI_Pin GPIO_PIN_15
#define SD_MOSI_GPIO_Port GPIOB
#define SD_CS_Pin GPIO_PIN_6
#define SD_CS_GPIO_Port GPIOC
#define SWD_IO_Pin GPIO_PIN_13
#define SWD_IO_GPIO_Port GPIOA
#define SWD_CLK_Pin GPIO_PIN_14
#define SWD_CLK_GPIO_Port GPIOA
#define Encode_1_Pin GPIO_PIN_11
#define Encode_1_GPIO_Port GPIOC
#define Scale_Axis_Pin GPIO_PIN_4
#define Scale_Axis_GPIO_Port GPIOB

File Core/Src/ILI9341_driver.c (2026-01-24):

#include "ILI9341_driver.h"

extern SPI_HandleTypeDef hspi1;
uint16_t wave_y_min[SCREEN_WIDTH];
uint16_t wave_y_max[SCREEN_WIDTH];
uint16_t old_wave_y_min[SCREEN_WIDTH];
uint16_t old_wave_y_max[SCREEN_WIDTH];

static void ILI9341_WriteCommand(uint8_t cmd) {
	HAL_GPIO_WritePin(LCD_DCRS_PIN, GPIO_PIN_RESET);
	HAL_GPIO_WritePin(LCD_CS_PIN, GPIO_PIN_RESET);
	HAL_SPI_Transmit(&hspi1, &cmd, 1 , HAL_MAX_DELAY);
	HAL_GPIO_WritePin(LCD_CS_PIN, GPIO_PIN_SET);
}

static void ILI9341_WriteData(uint8_t *data, uint16_t size) {
	HAL_GPIO_WritePin(LCD_DCRS_PIN, GPIO_PIN_SET);
	HAL_GPIO_WritePin(LCD_CS_PIN, GPIO_PIN_RESET);
	HAL_SPI_Transmit(&hspi1, data, size , HAL_MAX_DELAY);
	HAL_GPIO_WritePin(LCD_CS_PIN, GPIO_PIN_SET);
}

//Reset Display
void ILI9341_Reset(void) {
	HAL_GPIO_WritePin(LCD_RESET_PIN, GPIO_PIN_RESET);
	HAL_Delay(20);
	HAL_GPIO_WritePin(LCD_RESET_PIN, GPIO_PIN_SET);
	HAL_Delay(120);
}

//Initialise Display
void ILI9341_Init(void) {
	ILI9341_Reset();
	ILI9341_WriteCommand(0x028); //Display OFF

	uint8_t data = 0x55; //16-bit colour
	ILI9341_WriteCommand(0x3A); //Pixel Format Set
	ILI9341_WriteData(&data, 1);

	ILI9341_WriteCommand(0x29); //Display On

}

//Set Address Window
void ILI9341_SetAddressWindow(uint16_t x0, uint16_t y0, uint16_t x1, uint16_t y1) {
	uint8_t data[4];

	ILI9341_WriteCommand(0x2A); //Column Address Set
	data[0] = x0 >> 8;
	data[1] = x0 & 0xFF;
	data[2] = x1 >> 8;
	data[3] = x1 & 0xFF;
	ILI9341_WriteData(data, 4);

	ILI9341_WriteCommand(0x2B); //Page Address Set
	data[0] = y0 >> 8;
	data[1] = y0 & 0xFF;
	data[2] = y1 >> 8;
	data[3] = y1 & 0xFF;
	ILI9341_WriteData(data, 4);

	ILI9341_WriteCommand(0x2C); //Memory Write
}

//Draw Pixel
void ILI9341_DrawPixel(uint16_t x, uint16_t y, uint16_t colour) {
	ILI9341_SetAddressWindow(x, y, x, y);
	uint8_t data[2] = { colour >> 8, colour & 0xFF };
	ILI9341_WriteData(data, 2);
}

//Clear Display
void ILI9341_Clear(uint16_t color) {
	ILI9341_SetAddressWindow(0, 0, ILI9341_WIDTH - 1, ILI9341_HEIGHT - 1);
	uint8_t data[2] = { color >> 8, color & 0xFF };

	for (uint32_t i = 0; i < ILI9341_WIDTH * ILI9341_HEIGHT; i++) {
		ILI9341_WriteData(data, 2);
	}
}

//Draw Lines
void ILI9341_DrawVSpan(uint16_t x, uint16_t y0, uint16_t y1, uint16_t colour) {
	if (y0>y1) {
		uint16_t temp = y0;
		y0 = y1;
		y1 = temp;
	}
	if (y1>=ILI9341_HEIGHT) {y1 = ILI9341_HEIGHT-1;};
	ILI9341_SetAddressWindow(x, y0, x, y1);
	uint8_t data[2] = { colour >> 8, colour & 0xFF };
	for (uint16_t y=y0; y<=y1; y++) {
		ILI9341_WriteData(data, 2);
	}
}

void ILI9341_DrawHSpan(uint16_t y, uint16_t x0, uint16_t x1, uint16_t colour) {
	if (x0>x1) {
		uint16_t temp = x0;
		x0 = x1;
		x1 = temp;
	}
	if (x1>=ILI9341_WIDTH) {x1 = ILI9341_WIDTH-1;};
	ILI9341_SetAddressWindow(x0, y, x1, y);
	uint8_t data[2] = { colour >> 8, colour & 0xFF };
	for (uint16_t x=x0; x<=x1; x++) {
		ILI9341_WriteData(data, 2);
	}
}

//Draw Grid
void ILI9341_DrawAxis(uint8_t ydivs, uint8_t xdivs) {
	ILI9341_DrawHSpan(ILI9341_HEIGHT / 2, 20, ILI9341_WIDTH - 20, BLUE); //Horizontal Centre Line
	for (uint8_t i=1; i<=ydivs; i++){
		uint16_t dy = (uint16_t)(100.0f/ydivs)*i;
		ILI9341_DrawHSpan((ILI9341_HEIGHT/2) + dy, 20, ILI9341_WIDTH - 20, WHITE); // Adds y-grid lines
		ILI9341_DrawHSpan((ILI9341_HEIGHT/2) - dy, 20, ILI9341_WIDTH - 20, WHITE);
	}
	ILI9341_DrawVSpan(20, 0, ILI9341_HEIGHT, BLUE);  //Vertical x=0 Line
	for (uint8_t i=1; i<=xdivs; i++){
		ILI9341_DrawVSpan(20+((280.0f/xdivs)*i), 0, ILI9341_HEIGHT, WHITE);  //Adds x-grid lines
	}
}

//Map ADC value to Y coordinate
uint32_t ILI9341_MapADCtoY(float Vin, float yDIV) {
	float vpp = 2.0f * yDIV * Y_DIVISIONS; //Total volts displayed on screen
	float vtop = vpp / 2.0f; //Voltage at top of screen
	float vbot = -vpp / 2.0f; //Voltage at bottom of screen
	float vloc = (Vin - vbot) / (vtop - vbot); //Location of Vin between vtop and vbot (0 to 1)

	float y = 220.0f - (vloc * (220.0f - 20.0f)); //Map to Y coordinate (20 to 220)

	if (y < 20.0f) {y = 20.0f;}
	if (y > 220.0f) {y = 220.0f;}
	return (uint16_t)y;
}

uint16_t ILI9341_MapTimetoX(uint16_t t, uint16_t points) {
	//Between 20 -> 280
	//20 at t=0
	//280 at t=points-1
	return 20 + (uint16_t)((float)t * (280.0f - 20.0f) / (float)(points - 1));

}

void BuildWavefromBuffer(float *buffer, uint16_t points, float yDiv) {
	for (uint16_t i=20; i<280; i++) {
		wave_y_min[i] = 0xFFFF;
		wave_y_max[i] = 0;
	}
	for (uint16_t i=0; i<points; i++) {
		uint16_t x = ILI9341_MapTimetoX(i, points);
		uint16_t y = ILI9341_MapADCtoY(buffer[i], yDiv); //Using 0.5V/div for min/max calculation
		if (y < wave_y_min[x]) {
			wave_y_min[x] = y;
		}
		if (y > wave_y_max[x]) {
			wave_y_max[x] = y;
		}
	}
}

//Plot Waveform
void ILI9341_PlotWaveform(float *buffer, float xDIV, float yDIV, uint16_t colour) {
	uint32_t time = (uint32_t)xDIV * (uint32_t)X_DIVISIONS;
	uint16_t points = (uint16_t)((float)time/Sample_period);
	BuildWavefromBuffer(buffer, points, yDIV);
	for (uint16_t x=20; x<280; x++) {
		if (wave_y_max[x] >= wave_y_min[x]) {
			ILI9341_DrawVSpan(x, wave_y_min[x], wave_y_max[x], colour);
		}
		old_wave_y_min[x] = wave_y_min[x];
		old_wave_y_max[x] = wave_y_max[x];
		wave_y_min[x] = 0xFFFF;
		wave_y_max[x] = 0;
	}
}

void ILI9341_ClearWaveform(void){
	for (uint16_t x=20; x<280; x++) {
		if (old_wave_y_max[x] >= old_wave_y_min[x]) {
			ILI9341_DrawVSpan(x, old_wave_y_min[x], old_wave_y_max[x], BLACK);
		}
	}
}

void ILI9341_ClearUI(void){
	ILI9341_SetAddressWindow(UI_LEFT_X, UI_TOP_Y, UI_RIGHT_X, UI_BOTTOM_Y);
	uint8_t data[2] = { BLACK >> 8, BLACK & 0xFF };

	for (uint32_t i = 0; i < (UI_RIGHT_X - UI_LEFT_X + 1) * (UI_BOTTOM_Y - UI_TOP_Y + 1); i++) {
		ILI9341_WriteData(data, 2);
	}
}

void ILI9341_UpdateVals(float xDIV, float yDIV, float Trig_Voltage){
	//Address window for text area (Top Bar)
	// 20<=x<=300
	// 220<=Y<=239
	//Write xDIV=##, yDIV=##, Trig=##V
	char buffer[32];
	ILI9341_ClearUI();
	//X_DIV
	sprintf(buffer, "X: %.2fus/div", xDIV*1e6f);
	ILI9341_DrawString(25,225, buffer, WHITE, BLACK);
	//Y_DIV
	sprintf(buffer, "Y: %.2fV/div", yDIV);
	ILI9341_DrawString(130,225, buffer, WHITE, BLACK);
	//TRIG_VOLTAGE
	sprintf(buffer, "Trig: %.2fV", Trig_Voltage);
	ILI9341_DrawString(230,225, buffer, WHITE, BLACK);
}

void ILI9341_DrawChar(uint16_t x, uint16_t y, char c, uint16_t color, uint16_t bgcolor) {
	if (c < 0x20 || c>0x7E) {return;} //Unsupported character
	const uint8_t *char_bitmap = font5x7[c - 0x20];

	for (uint8_t col=0; col<FONT_WIDTH; col++) {
		uint8_t line = char_bitmap[col];
		for (uint8_t row=0; row<FONT_HEIGHT; row++) {
			if (line & (1 << row)) {
				ILI9341_DrawPixel(x + col, y + row, color);
			}
			else {
				ILI9341_DrawPixel(x + col, y + row, bgcolor);
			}
		}
	}
}

void ILI9341_DrawString(uint16_t x, uint16_t y, char *str, uint16_t color, uint16_t bgcolor) {
	uint16_t cursor_x = x;
	while (*str) {
		ILI9341_DrawChar(cursor_x, y, *str, color, bgcolor);
		cursor_x += FONT_WIDTH + FONT_SPACING;
		str++;
	}
}

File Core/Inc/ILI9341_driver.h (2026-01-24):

#ifndef ILI9341_DRIVER_H
#define ILI9341_DRIVER_H

#include "stm32f4xx_hal.h"
#include "main.h"
#include <stdint.h>
#include <math.h>

#define BLACK 0x0000
#define WHITE 0xFFFF
#define RED 0xF800
#define GREEN 0x07E0
#define BLUE 0x001F
#define YELLOW 0xFFE0
#define CYAN 0x07FF
#define MAGENTA 0xF81F
#define ORANGE 0xFC00


#define ILI9341_WIDTH 320
#define ILI9341_HEIGHT 240

#define UI_TOP_Y 220
#define UI_BOTTOM_Y 239
#define UI_LEFT_X 20
#define UI_RIGHT_X 300

#define FONT_WIDTH 5
#define FONT_HEIGHT 7
#define FONT_SPACING 1

void ILI9341_Init(void);
void ILI9341_Clear(uint16_t color);
void ILI9341_DrawPixel(uint16_t x, uint16_t y, uint16_t color);
void ILI9341_DrawHSpan(uint16_t y, uint16_t x0, uint16_t x1, uint16_t color);
void ILI9341_DrawVSpan(uint16_t x, uint16_t y0, uint16_t y1, uint16_t color);
void ILI9341_SetAddressWindow(uint16_t x0, uint16_t y0, uint16_t x1, uint16_t y1);
void ILI9341_DrawAxis(uint8_t ydivs, uint8_t xdivs);
float ILI9341_MapADCtoY(float Vin, float yDIV);
uint16_t ILI9341_MapTimetoX(uint16_t t, uint16_t points);
void ILI9341_PlotWaveform(float *buffer, float xDIV, float yDIV, uint16_t color);
void BuildWavefromBuffer(float *buffer, uint16_t points, float yDIV);
void ILI9341_UpdateVals(float xDIV, float yDIV, float Trig_Voltage);
void ILI9341_ClearWaveform(void);
void ILI9341_ClearUI(void);
void ILI9341_DrawChar(uint16_t x, uint16_t y, char c, uint16_t color, uint16_t bgcolor);
void ILI9341_DrawString(uint16_t x, uint16_t y, char *str, uint16_t color, uint16_t bgcolor);



#endif //ILI9341_DRIVER_H

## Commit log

2026-01-22 Started main code and most of ILI9341 driver
2026-01-23 Edited Schematic
    [ADC_Input.kicad_sch, Osciliscope PCB.kicad_pcb, Osciliscope PCB.kicad_sch]
2026-01-23 Started main loop and added changes to screen function for allign
    [ADC_Input.kicad_sch]
2026-01-23 Cleaned up and fixed code
    [ILI9341_driver.c, main.c, main.h]
2026-01-24 Finished code, bug checked and also wrote code to print UI with ASCII font
    [ILI9341_driver.c, ILI9341_driver.h, main.c]
2026-01-24 Finished PCB
    [Osciliscope PCB.kicad_pcb, Osciliscope PCB.kicad_sch]
2026-01-24 Removed old files
    [Osciliscope_PCB_BOM.csv, designators.csv, positions.csv]

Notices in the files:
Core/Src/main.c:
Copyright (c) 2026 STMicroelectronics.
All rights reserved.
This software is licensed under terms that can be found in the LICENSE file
